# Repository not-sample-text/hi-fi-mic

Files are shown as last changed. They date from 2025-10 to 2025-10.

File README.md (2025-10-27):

# Hi-Fi Microphone PCB

A custom PCB for the high-fidelity microphone project by DIY Perks, redesigned from the original stripboard version for a cleaner and more reliable build.

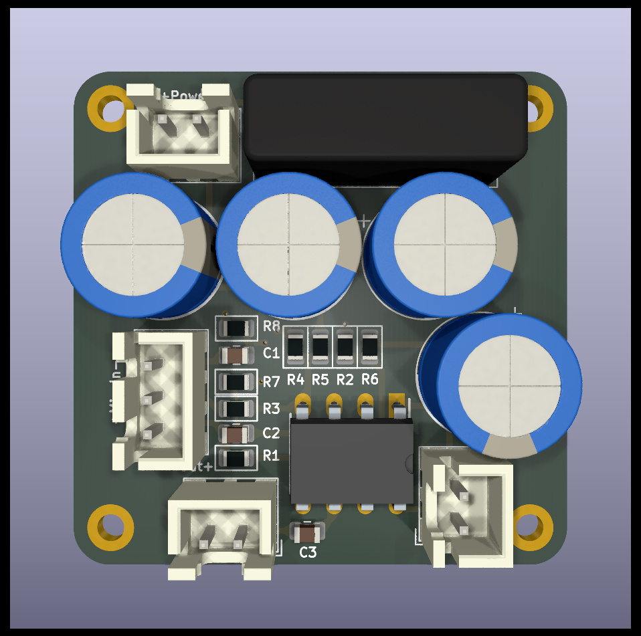
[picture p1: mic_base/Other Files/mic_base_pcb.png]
PCB Front

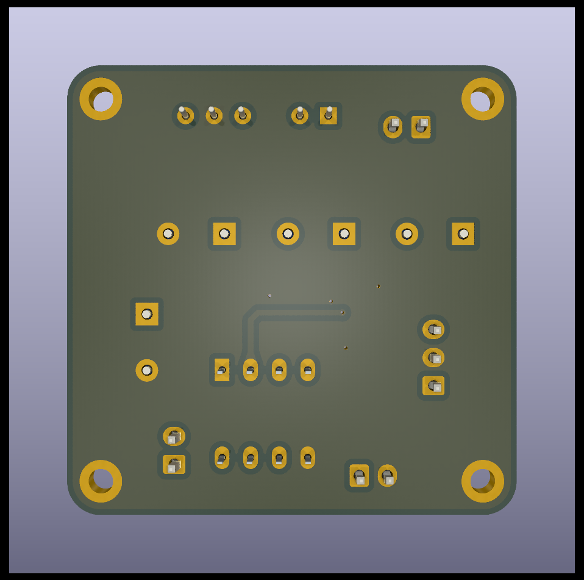
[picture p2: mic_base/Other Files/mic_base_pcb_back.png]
PCB Back


## Table of Contents

- [Overview](#overview)
- [Features](#features)
- [PCB Design](#pcb-design)
- [Project Structure](#project-structure)
- [Getting Started](#getting-started)
- [Credits](#credits)

## Overview

This project provides a dedicated PCB for the Hi-Fi microphone circuit originally demonstrated by [DIY Perks](https://www.youtube.com/watch?v=LoQu3XXIayc). While the original build used a stripboard, this KiCad project offers a custom-designed PCB, making the assembly process more straightforward and the final product more durable and professional.

## Features

- **Dedicated PCB Design**: Eliminates complex wiring on stripboard, improving reliability.
- **Compact & Clean Layout**: Components are organized for a tidy and space-efficient build.
- **Easy Assembly**: Through-hole components and clear labeling simplify the soldering process.
- **Professional Finish**: Achieve a high-quality result comparable to commercial products.

## PCB Design

The project was designed in KiCad and consists of a single two-layer board.

- **[Schematic PDF](<mic_base/Other Files/mic_base_schematic.pdf>)**
- **[PCB Layout PDF](<mic_base/Other Files/mic_base_layout.pdf>)**

### PCB Renders

| Front View | Back View | Initial Design |
| :---: | :---: | :---: |
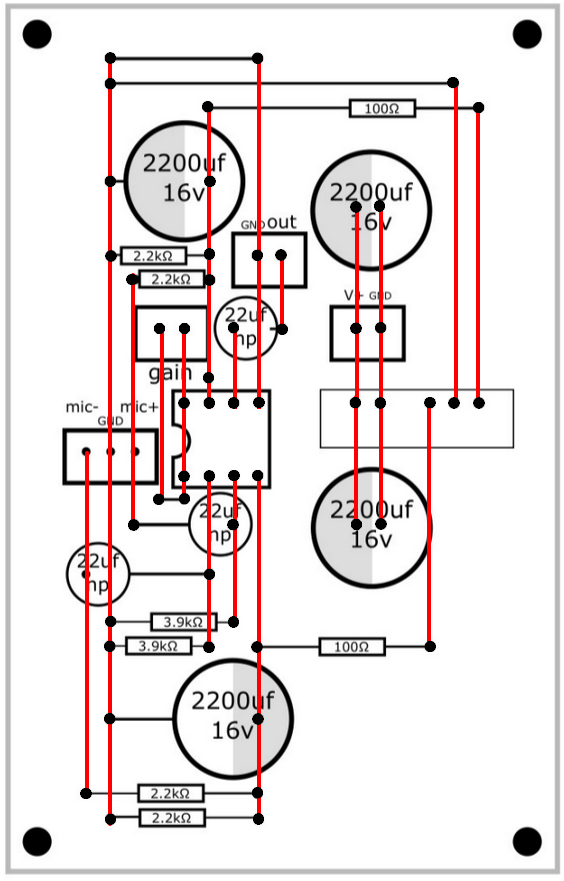
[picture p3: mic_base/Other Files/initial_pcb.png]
Initial PCB Design
| PCB Front | PCB Back |  |

## Project Structure

```
hi-fi-mic/
├── Imports/                  # Custom 3D models, footprints, and symbols
├── Other Files/              # Documentation (PDFs) and images
├── mic_base.kicad_pcb        # KiCad PCB layout file
├── mic_base.kicad_pro        # Main KiCad project file
├── mic_base.kicad_sch        # KiCad schematic file
└── README.md                 # This file
```

## Getting Started

### Hardware Assembly

1.  **Manufacture the PCB**: Use the KiCad project files to export Gerbers and order the board from a PCB fabrication service.
2.  **Gather Components**: Refer to the schematic for the complete Bill of Materials (BOM).
3.  **Solder Components**: Assemble the board, starting with the lowest-profile components first.
4.  **Testing**: Follow the testing and calibration steps shown in the original [DIY Perks video](https://www.youtube.com/watch?v=LoQu3XXIayc).

### Opening the Project

1.  Install [KiCad](https://www.kicad.org/) 7.0 or later.
2.  Open the `mic_base.kicad_pro` file to access the schematic and PCB layout.

## Credits

- **Original Circuit Concept**: [DIY Perks](https://www.youtube.com/c/DIYPerks)
- **PCB Redesign**: This project.

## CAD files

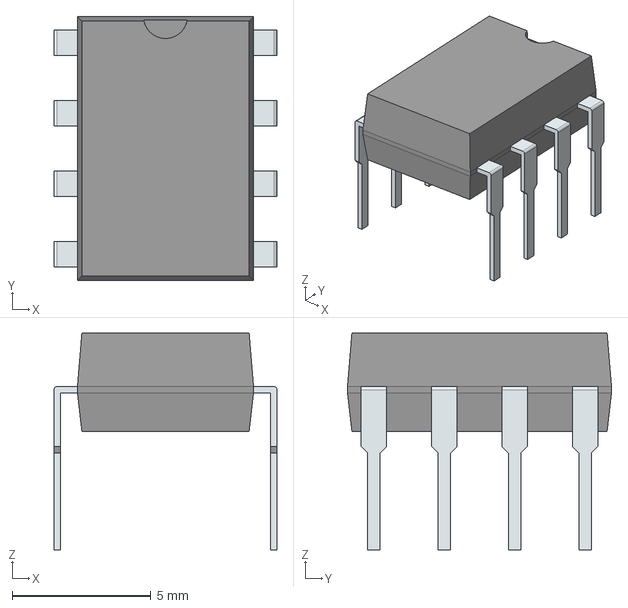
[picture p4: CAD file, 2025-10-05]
mic_base/Imports/3d/1512P08-U.stp
8.04 x 9.52 x 7.82 mm
PinsArrayLR

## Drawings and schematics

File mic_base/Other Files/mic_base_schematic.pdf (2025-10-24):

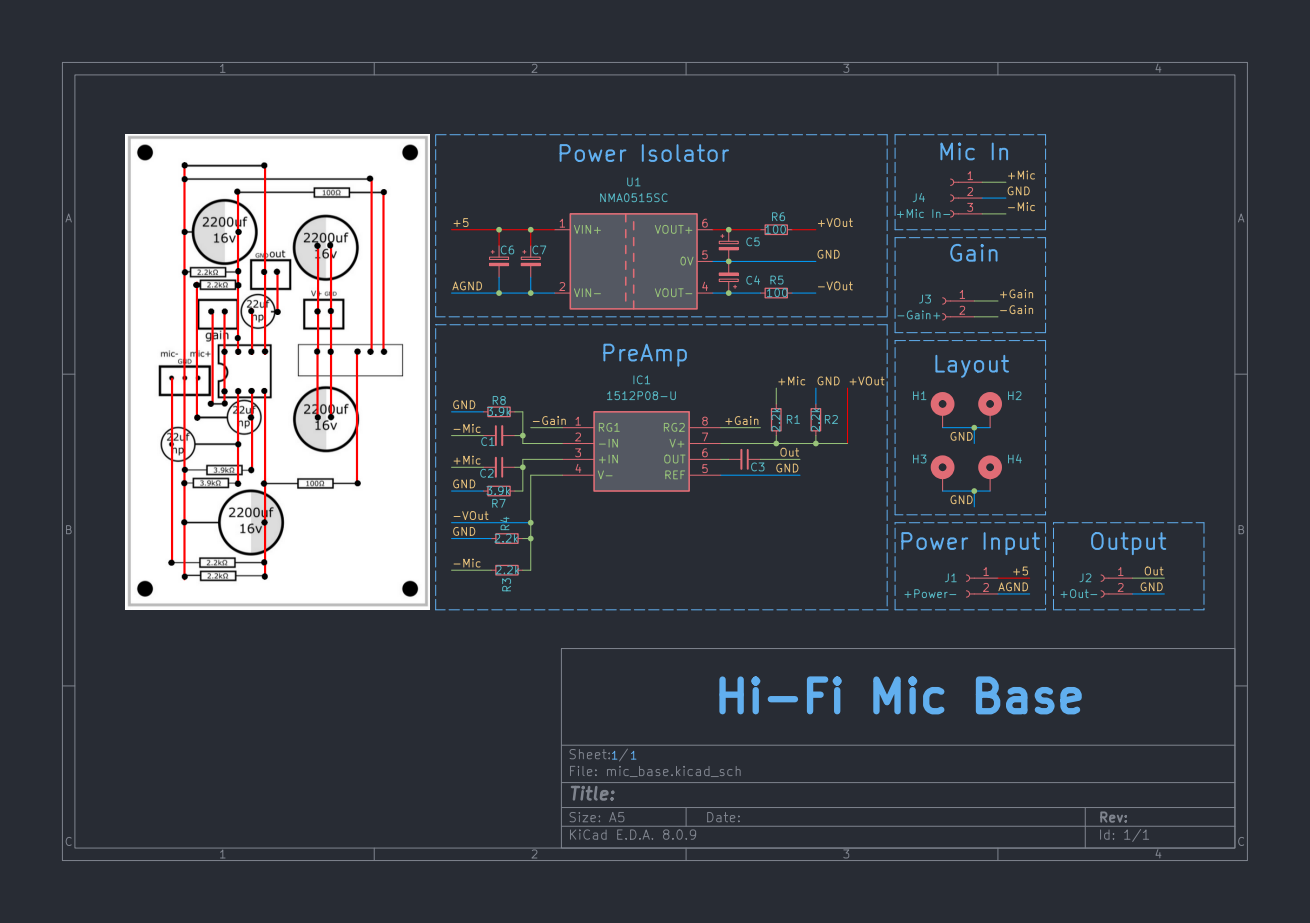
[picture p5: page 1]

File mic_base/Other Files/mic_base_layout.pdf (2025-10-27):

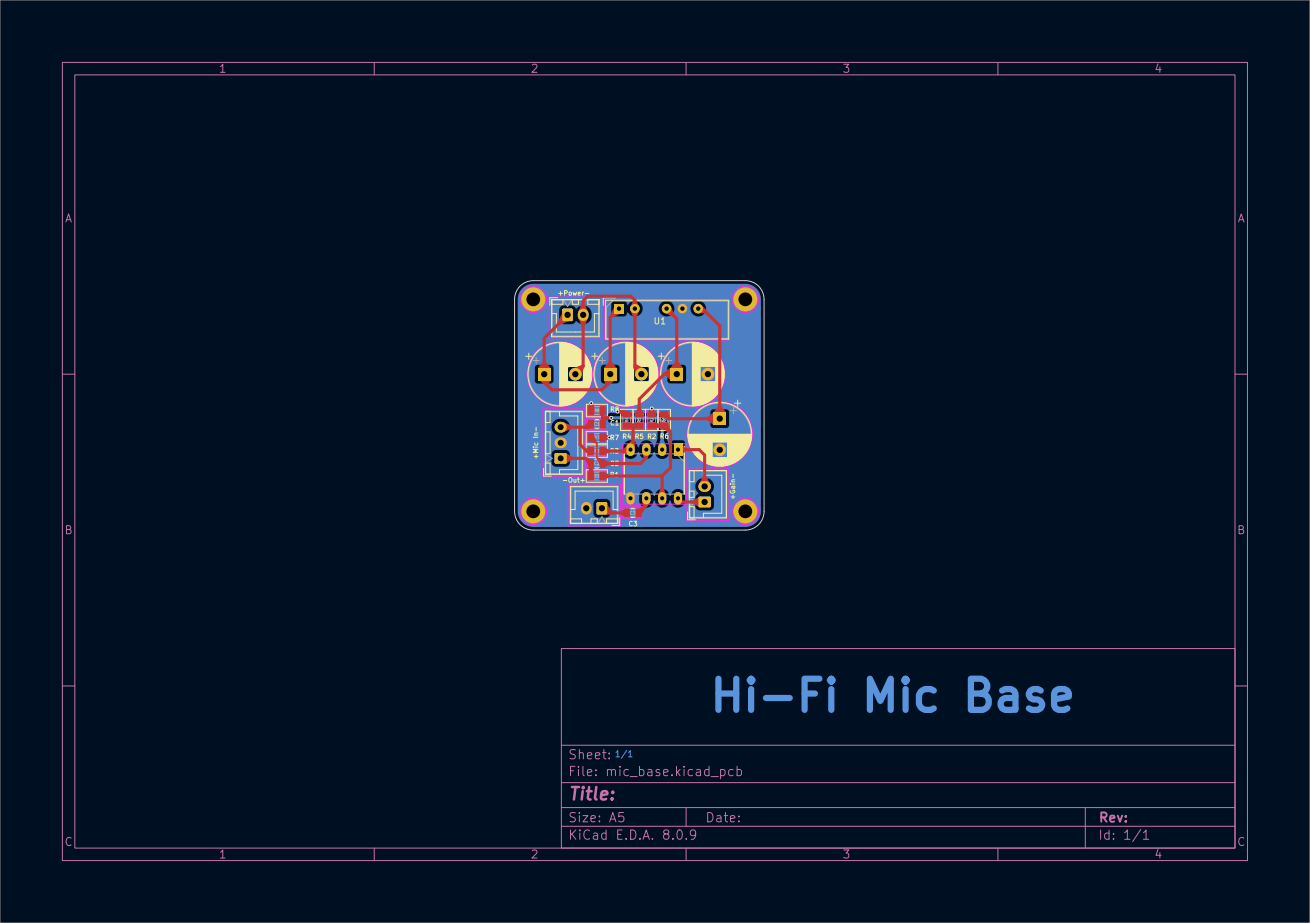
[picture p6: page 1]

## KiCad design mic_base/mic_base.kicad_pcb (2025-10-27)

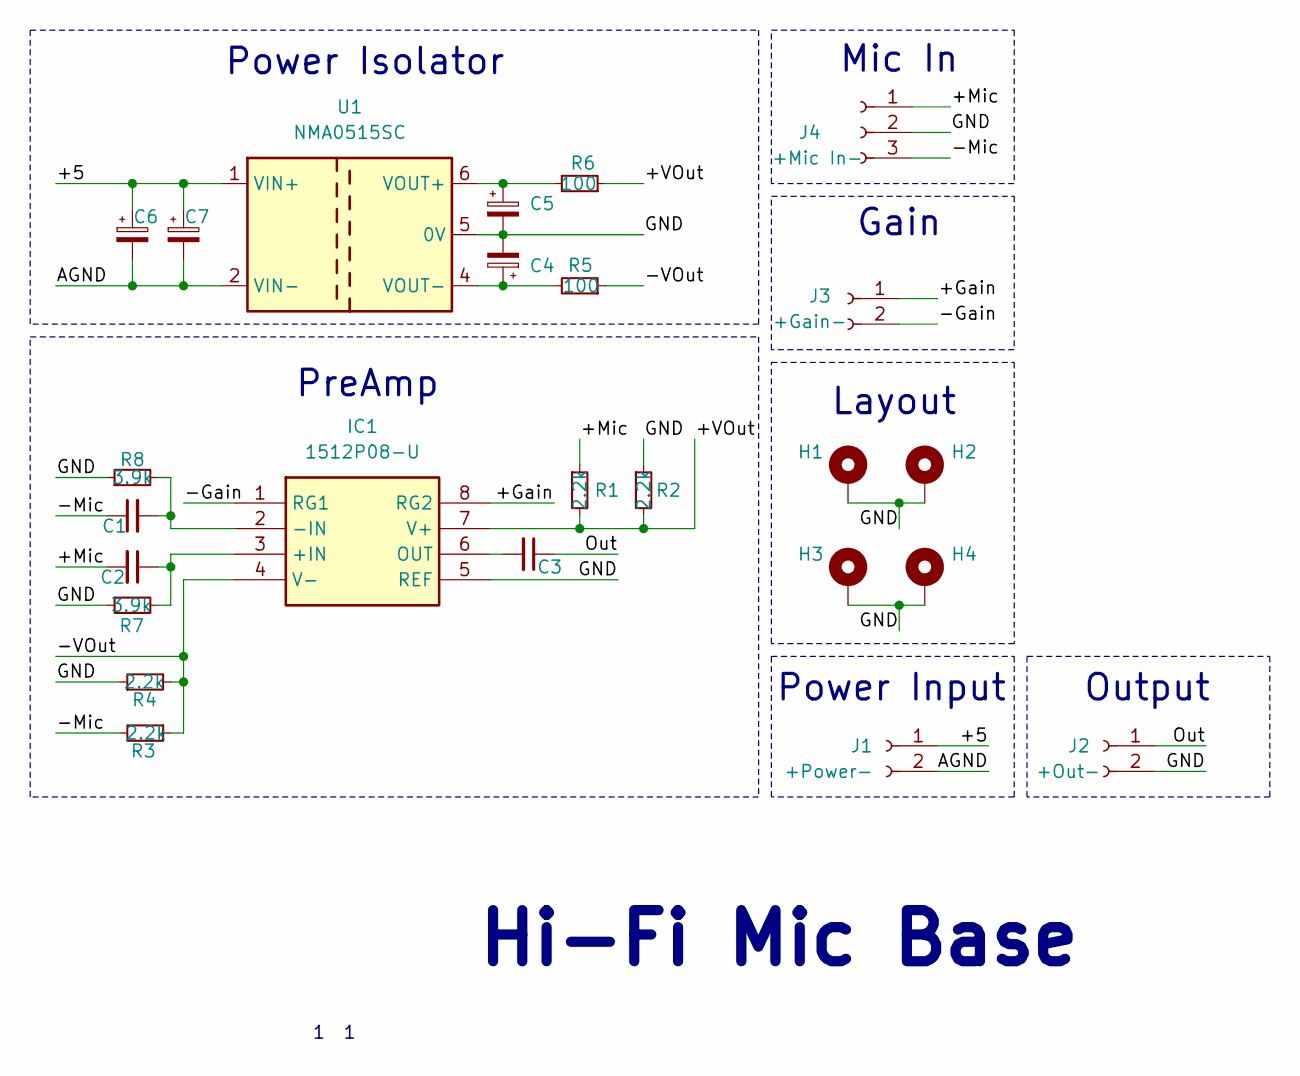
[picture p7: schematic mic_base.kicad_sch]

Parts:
C1, C2, C3: 22uF; C_0805_2012Metric
C4, C5, C6, C7: 2200uF; CP_Radial_D10.0mm_P5.00mm
H1, H2, H3, H4: MountingHole_Pad; MountingHole_2.2mm_M2_DIN965_Pad
IC1: 1512P08-U; DIP781W46P254L952H432Q8N; Mouser Part Number 887-1512P08-U
J1: +Power-; JST_XH_B2B-XH-A_1x02_P2.50mm_Vertical
J2: +Out-; JST_XH_B2B-XH-A_1x02_P2.50mm_Vertical
J3: +Gain-; JST_XH_B2B-XH-A_1x02_P2.50mm_Vertical
J4: +Mic In-; JST_XH_B3B-XH-A_1x03_P2.50mm_Vertical
R1, R2, R3, R4: 2.2k; R_0805_2012Metric
R5, R6: 100; R_0805_2012Metric
R7, R8: 3.9k; R_0805_2012Metric
U1: NMA0515SC; Converter_DCDC_Murata_NMAxxxxSC_THT

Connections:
/+5: C6.1, C7.1, J1.1, U1.1 (VIN+)
/+Gain: IC1.8 (RG2), J3.1
/+Mic: C2.2, J4.1, R1.1
/+VOut: IC1.7 (V+), R1.2, R2.2, R6.1
/-Gain: IC1.1 (RG1), J3.2
/-Mic: C1.1, J4.3, R3.2
/-VOut: IC1.4 (V-), R3.1, R4.2, R5.1
/AGND: C6.2, C7.2, J1.2, U1.2 (VIN-)
/GND: C4.2, C5.2, H1.1, H2.1, H3.1, H4.1, IC1.5 (REF), J2.2, J4.2, R2.1, R4.1, R7.1, R8.1, U1.5 (0V)
/Out: C3.1, J2.1
unnamed: C2.1, IC1.3 (+IN), R7.2
unnamed: C1.2, IC1.2 (-IN), R8.2
unnamed: C3.2, IC1.6 (OUT)
unnamed: C5.1, R6.2, U1.6 (VOUT+)
unnamed: C4.1, R5.2, U1.4 (VOUT-)

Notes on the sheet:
Output
Gain
PreAmp
Power Isolator
Mic In
Layout
Power Input
Hi-Fi Mic Base

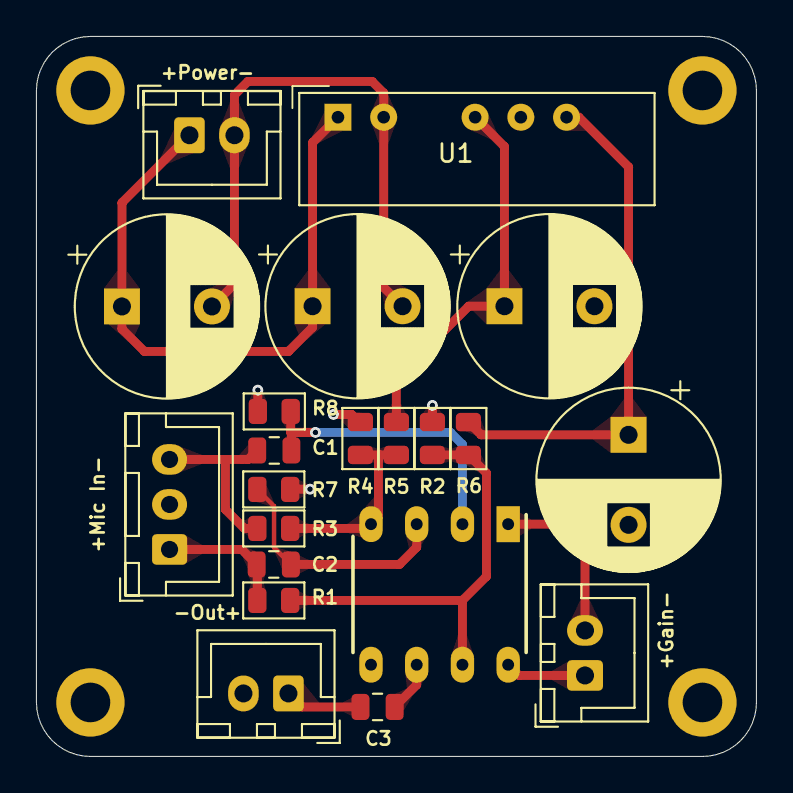
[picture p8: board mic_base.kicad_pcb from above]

Board: 2 copper layers, 40.0 x 40.0 mm, 25 parts (0 on the bottom side), 15 nets.

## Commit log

2025-10-14 basically done, maybe add some finishing touches later
    [mic_base.kicad_pcb, mic_base.kicad_sch]
2025-10-24 moved capacitors, made pcb smaller
    [mic_base.kicad_pcb, mic_base.kicad_sch]
2025-10-24 added images and readme
    [mic_base.kicad_pcb]
2025-10-26 changed resistors pin pitch from 7 to 5, compressed the board more
    readme to be updated
    [mic_base.kicad_pcb, mic_base.kicad_sch]
2025-10-27 changed footprints to 0805 smds, rewrote the readme
    [mic_base.kicad_pcb, mic_base.kicad_sch]
